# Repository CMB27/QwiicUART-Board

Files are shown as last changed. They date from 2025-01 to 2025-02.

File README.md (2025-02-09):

# QwiicUART Board
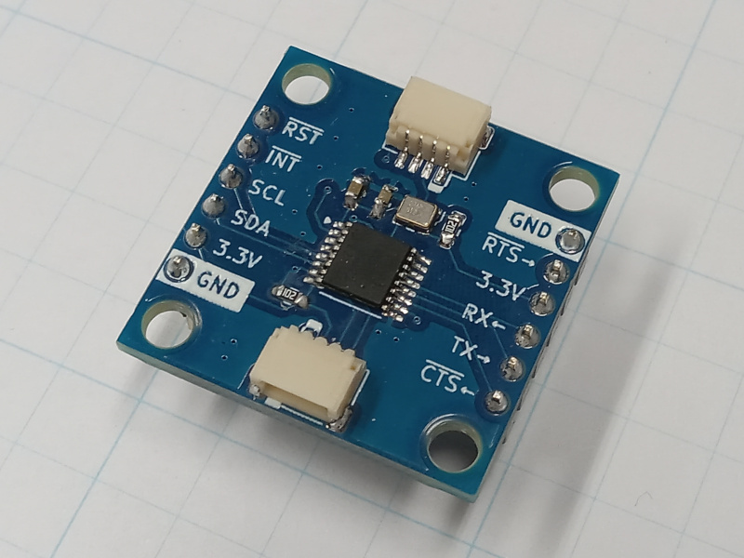
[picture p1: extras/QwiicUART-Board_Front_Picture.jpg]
Qwiic UART Front View


Have you ever needed another Serial (UART) port, but your microcontroller doesn't have any more.
This board allows you to add up to four Serial ports via the Qwiic system.

This is a breakout board for the NXP SC16IS741A.
The SC16IS741A is a UART controlled using an I<sup>2</sup>C or SPI interface.
This board is only setup to be able to utilize the I<sup>2</sup>C interface.

> [!NOTE]
> This design is distributed WITHOUT ANY EXPRESS OR IMPLIED WARRANTY, INCLUDING OF MERCHANTABILITY, SATISFACTORY QUALITY AND FITNESS FOR A PARTICULAR PURPOSE.

> [!WARNING]
> Applying voltages higher than 3.3V to any I/O pin could damage the board.

### Documentation
- [Schematic](QwiicUART-Board.pdf)
- [KiCad Source Files](src)
- [QwiicUART Library](https://github.com/CMB27/QwiicUART-Library)
- [SparkFun Qwiic Landing Page](https://www.sparkfun.com/qwiic)
- [NXP SC16IS741A Datasheet](https://www.nxp.com/docs/en/data-sheet/SC16IS741A.pdf)

## Components

### Circuit Board Specifications
- Board Length: **25.4 mm**
- Board Width: **25.4 mm**
- Board Thickness: **1.6 mm**
- Substrate Material: **FR4**
- Copper Layers: **2**
- Copper Thickness: **1 oz**
- Soldermask Color: **Any** (Blue Suggested)
- Surface Finish: **Any** (HASL Lead-Free Suggested)
- Smallest Hole Diameter: **0.3 mm [11.8 mil]**
- Smallest Trace Width: **0.2 mm [7.8 mil]**
- Smallest Trace Spacing: **0.2 mm [7.8 mil]**

### Purchase Components
| References | Quantity | Manufacturer | Part Number | Description |
| :--- | :---: | :--- | :--- | :--- |
| C1, C2 | 2 | Samsung | CL10B104KB8NNWC | 0.1uF 0603 Capacitor  |
| J1, J2 | 2 | JST | SM04B-SRSS-TB(LF)(SN)  | 4-Position Connector  |
| R1, R2 | 2 | YAGEO | RC0603JR-071KL | 1K Ohm 0603 Resistor  |
| U1 | 1 | NXP | SC16IS741AIPWJ | UART IC |
| X1 | 1 | ECS | ECS-2520MVLC-018-BN-TR | 1.8432 HMz Oscillator |

## Assembly
Qwiic UART Fabrication View

All components are assembled to the top side of the board.
See the image above for component locations.

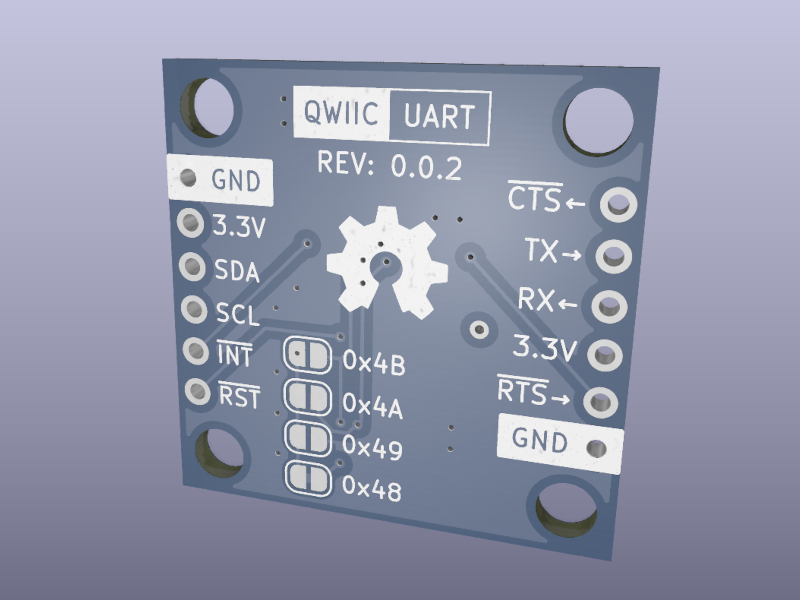
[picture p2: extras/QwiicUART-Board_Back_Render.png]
Qwiic UART Back View


On the back side of the board there are several solder jumper locations.
By default the lower `0x48` jumper is connected.
This connection can be cut and another jumper can be soldered to change the I<sup>2</sup>C address.

> [!WARNING]
> Powering up the board with more than one jumper soldered/connected could result in a short ciruit damaging the board.

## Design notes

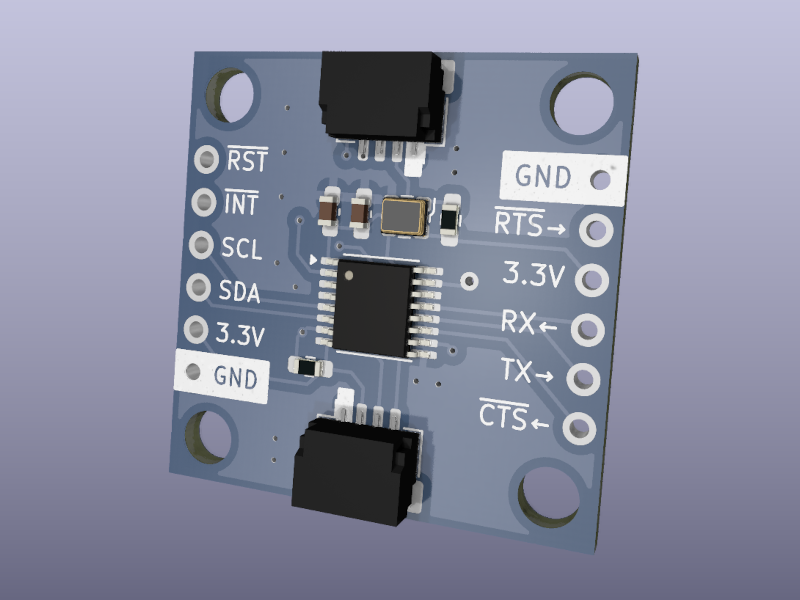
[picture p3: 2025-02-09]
extras/QwiicUART-Board_Front_Render.png

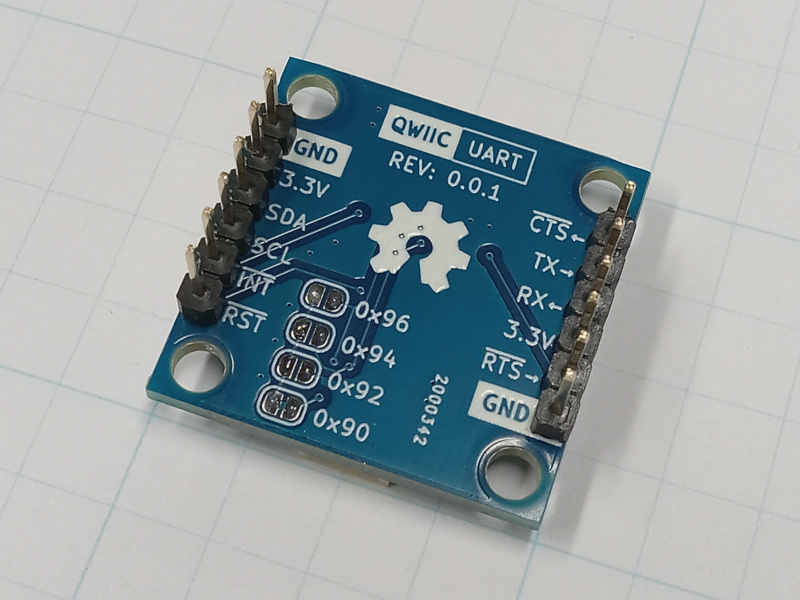
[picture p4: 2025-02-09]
extras/QwiicUART-Board_Back_Picture.jpg

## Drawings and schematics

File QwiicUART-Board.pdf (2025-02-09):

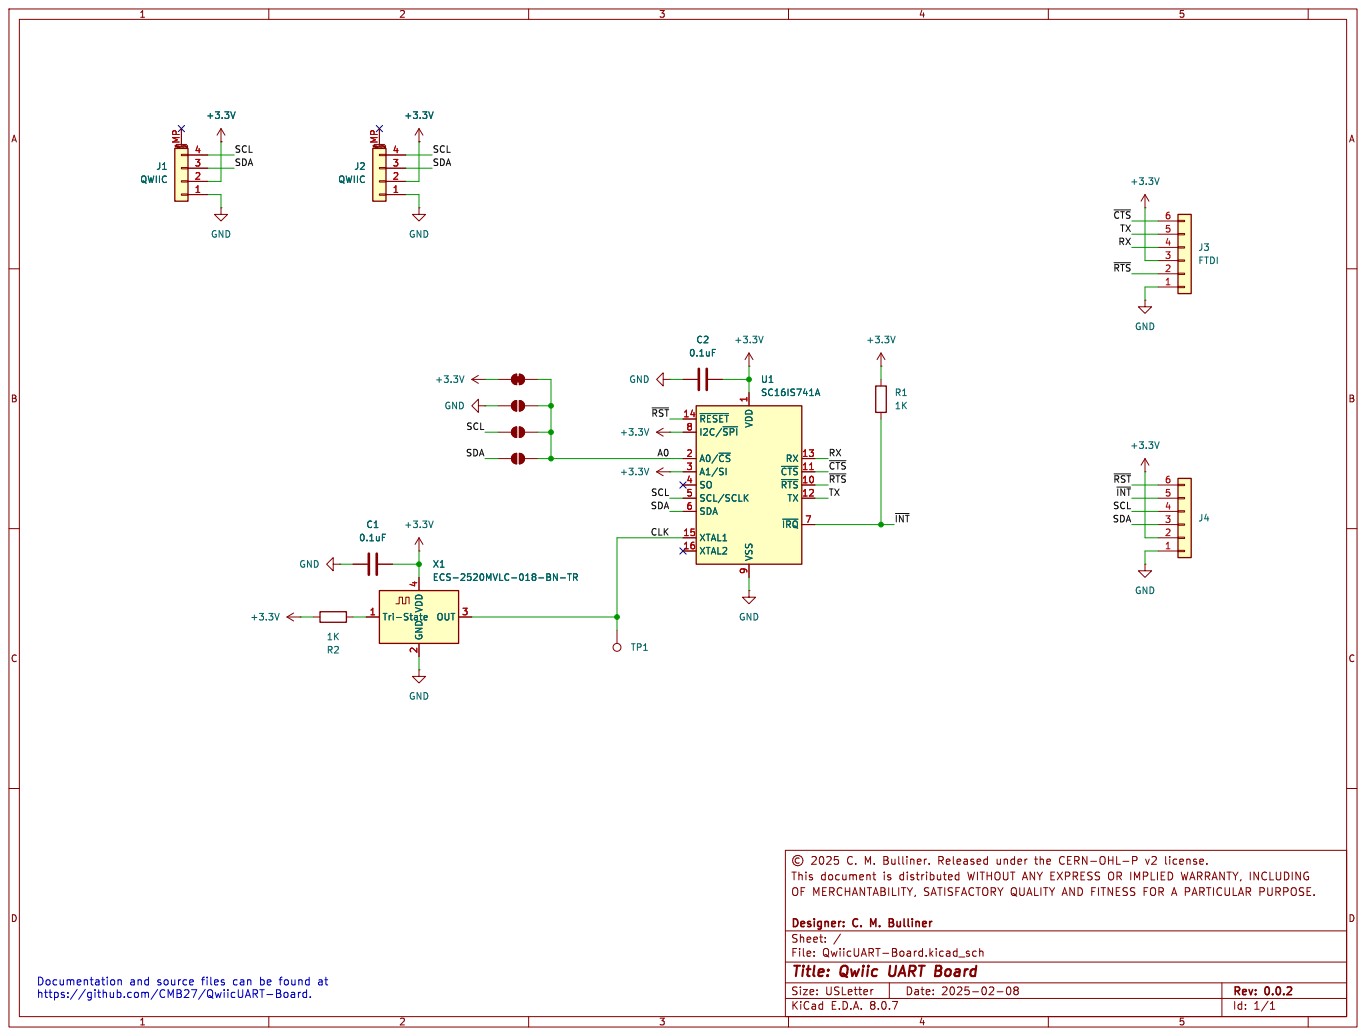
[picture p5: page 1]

4 X1ECS-2520MVLC-018-BN-TR GND GND

1 ~{RTS} 10 ~{CTS} 11 TX 12 RX 13 ~{RESET} 14 XTAL1 15 XTAL2 16 A0/~{CS} 2 A1/SI 3 SO 4 SCL/SCLK 5 SDA 6 ~{IRQ}7

Id: 1/1 Title: Qwiic UART Board

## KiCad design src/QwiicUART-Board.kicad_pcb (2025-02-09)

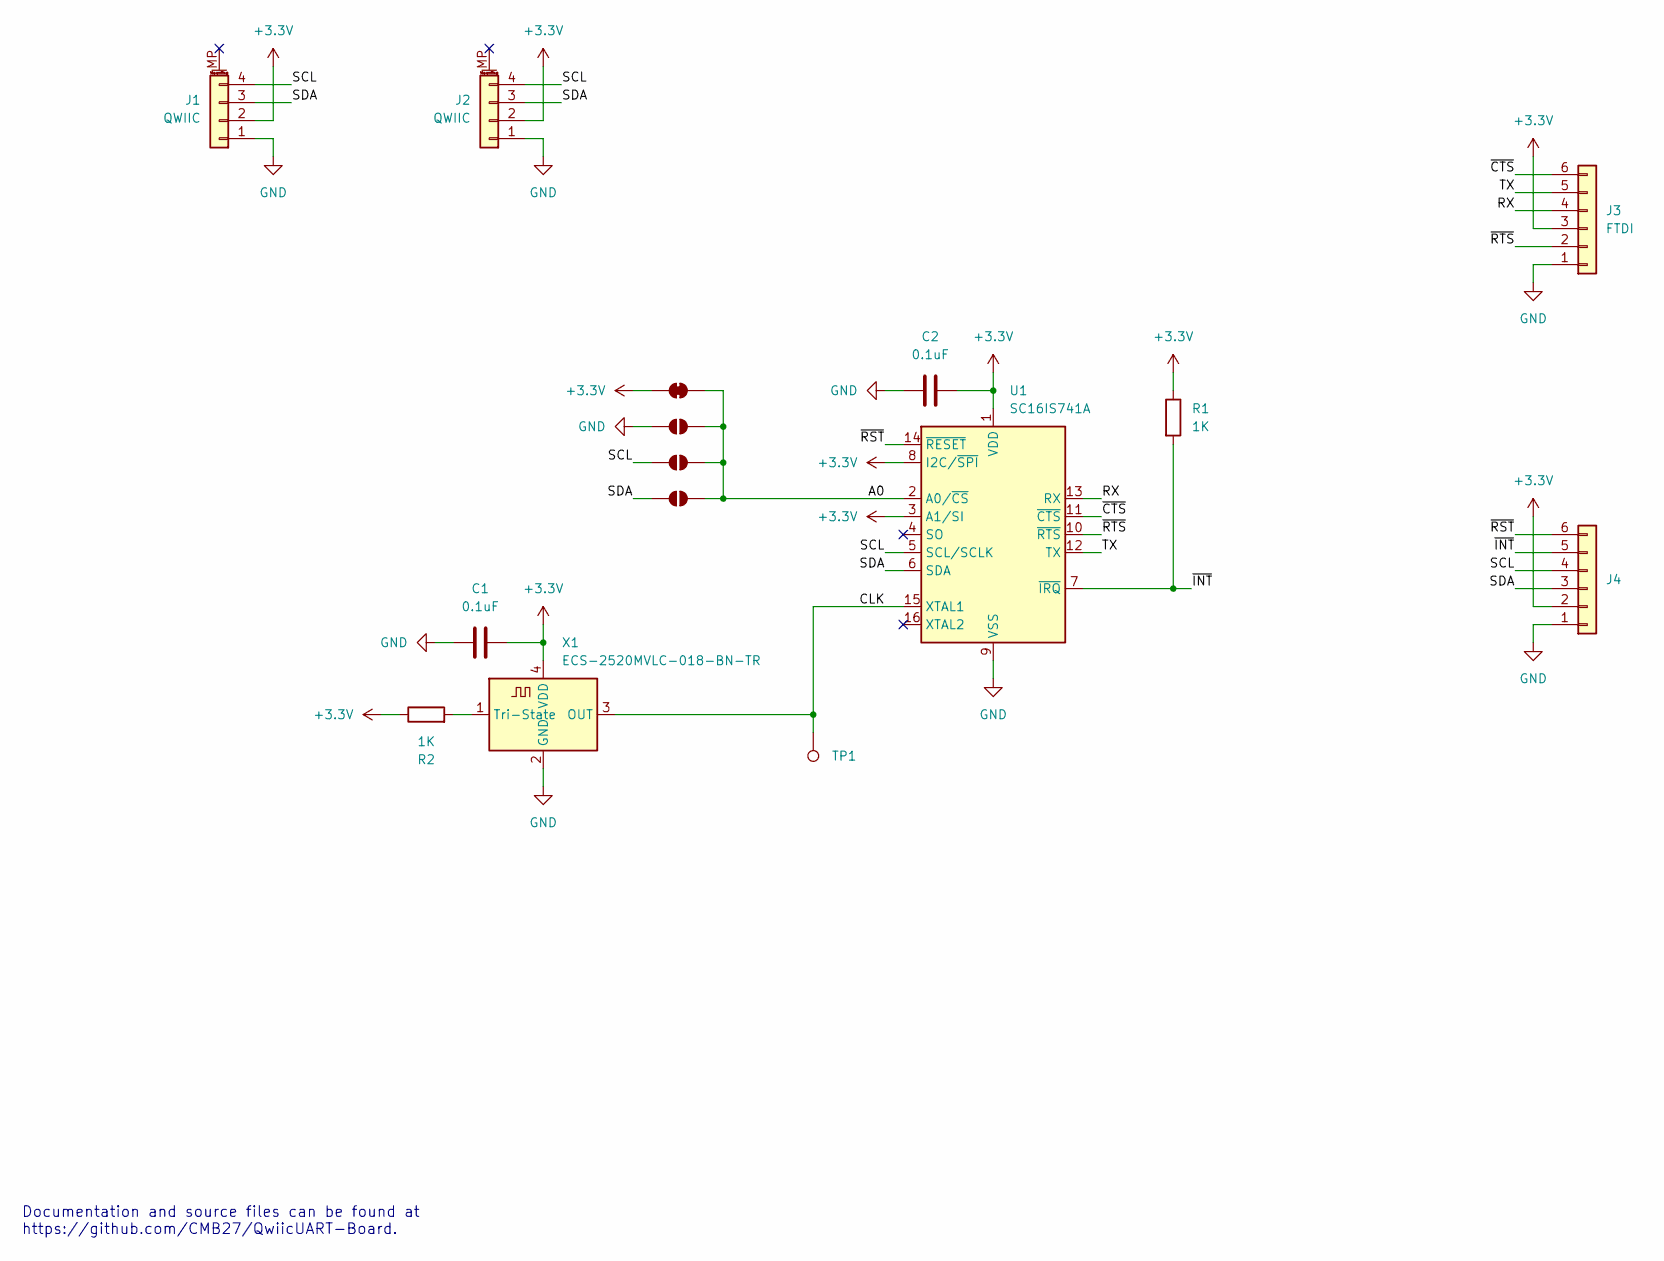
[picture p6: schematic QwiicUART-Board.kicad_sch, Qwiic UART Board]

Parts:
C1, C2: 0.1uF; C_0603_1608Metric_Pad1.08x0.95mm_HandSolder
J1, J2: QWIIC; JST_SH_SM04B-SRSS-TB_1x04-1MP_P1.00mm_Horizontal
J3: FTDI; PinHeader_1x06_P2.54mm
J4: PinHeader_1x06_P2.54mm
JP1: SolderJumper_2_Bridged; SolderJumper-2_P1.3mm_Bridged_RoundedPad1.0x1.5mm
JP2, JP3, JP4: SolderJumper_2_Open; SolderJumper-2_P1.3mm_Open_RoundedPad1.0x1.5mm
R1, R2: 1K; R_0603_1608Metric_Pad0.98x0.95mm_HandSolder
TP1: TestPoint; TestPoint_THTPad_D1.0mm_Drill0.5mm
U1: SC16IS741A; TSSOP-16_4.4x5mm_P0.65mm
X1: ECS-2520MVLC-018-BN-TR; Oscillator_SMD_ECS_2520MV-xxx-xx-4Pin_2.5x2.0mm

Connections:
+3.3V: C1.2, C2.2, J1.2, J2.2, J3.3, J4.2, JP1.1 (A), R1.1, R2.1, U1.1 (VDD), U1.3 (A1/SI), U1.8 (I2C/~SPI), X1.4 (VDD)
/A0: JP1.2 (B), JP2.2 (B), JP3.2 (B), JP4.2 (B), U1.2 (A0/~CS)
/CLK: TP1.1, U1.15 (XTAL1), X1.3 (OUT)
/RX: J3.4, U1.13 (RX)
/SCL: J1.4, J2.4, J4.4, JP3.1 (A), U1.5 (SCL/SCLK)
/SDA: J1.3, J2.3, J4.3, JP4.1 (A), U1.6 (SDA)
/TX: J3.5, U1.12 (TX)
/~CTS: J3.6, U1.11 (~CTS)
/~INT: J4.5, R1.2, U1.7 (~IRQ)
/~RST: J4.6, U1.14 (~RESET)
/~RTS: J3.2, U1.10 (~RTS)
GND: C1.1, C2.1, J1.1, J2.1, J3.1, J4.1, JP2.1 (A), U1.9 (VSS), X1.2 (GND)
unnamed: R2.2, X1.1 (Tri-State)

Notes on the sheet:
Documentation and source files can be found at https://github.com/CMB27/QwiicUART-Board.

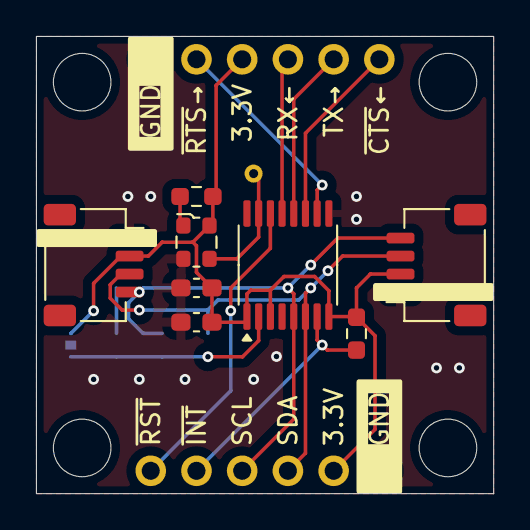
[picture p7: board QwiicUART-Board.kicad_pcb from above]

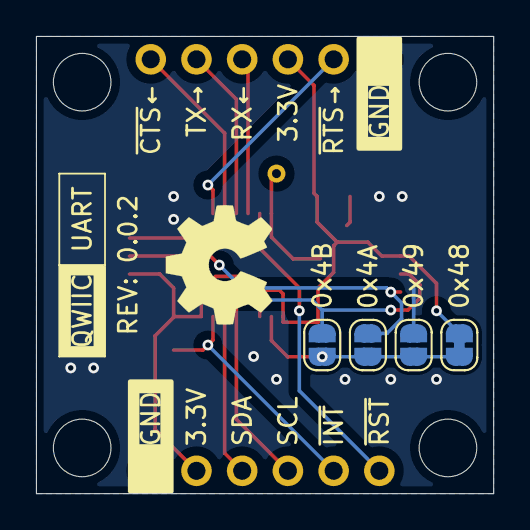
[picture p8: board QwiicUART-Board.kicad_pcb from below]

Board: 2 copper layers, 25.4 x 25.4 mm, 15 parts (4 on the bottom side), 13 nets.

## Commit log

2025-01-11 Made some refinements
    [Qwiic-UART.kicad_pcb, Qwiic-UART.kicad_sch]
2025-01-11 Finished board design
    [Qwiic-UART.kicad_pcb]
2025-01-12 Added/generated essential files
    [Qwiic-UART-B_Cu.gbr, Qwiic-UART-B_Mask.gbr, Qwiic-UART-B_Paste.gbr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]
2025-02-09 Changed repository name. Changed address numbers on back of board. Added a test point for the clock.
    [Qwiic-UART-B_Paste.gbr, Qwiic-UART-F_Mask.gbr, Qwiic-UART-F_Paste.gbr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]

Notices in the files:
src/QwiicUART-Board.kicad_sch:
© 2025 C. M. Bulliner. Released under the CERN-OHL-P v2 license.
